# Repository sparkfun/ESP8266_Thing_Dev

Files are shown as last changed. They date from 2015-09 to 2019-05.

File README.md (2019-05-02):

SparkFun ESP8266 Thing Development Board
========================================

SparkFun ESP8266 Thing Development Board

[*SparkFun ESP8266 Thing Development Board  (WRL-13711)*](https://www.sparkfun.com/products/13711)

The [SparkFun ESP8266 Thing Development Board](https://www.sparkfun.com/products/13711) is a breakout and development board for the ESP8266 WiFi SoC. Why the name? We lovingly call it the Thing because it's the perfect foundation for your Internet of Things (IoT) project. The ESP8266 is an extremely cost-effective WiFi module, that can be programmed just like any microcontroller, and wiggle I/O while it communicates with the world-wide-web.

This version of the [Thing](https://www.sparkfun.com/products/13231) equips the ESP8266 with an **onboard FTDI FT231X**, which is used to program the chip over a USB interface. No external programming board required! The ESP8266's I/O pins are broken out to two parallel, breadboard-compatible rows. And LEDs towards the inside of the board indicate power, communication, and status of the IC. The ESP8266’s maximum voltage is 3.6V, so the Thing Development Board has an onboard 3.3V regulator to deliver a safe, consistent voltage to the IC. That means the ESP8266’s I/O pins also run at 3.3V, you’ll need to level shift any 5V signals running into the IC.

Repository Contents
-------------------

* **/Hardware** - Eagle design files (.brd, .sch)
* **/Production** - Production panel files (.brd)

Documentation
--------------
* **[Hookup Guide](https://learn.sparkfun.com/tutorials/esp8266-thing-development-board-hookup-guide)** - Exhaustive hookup guide for the ESP8266 Thing Development Board.

Product Versions
----------------

* [KIT-15259](https://www.sparkfun.com/products/15259)- ESP8266 Thing Development Board in a starter kit.
* [WRL-13804](https://www.sparkfun.com/products/13804)- ESP8266 Thing Development Board with headers.
* [WRL-13711](https://www.sparkfun.com/products/13711)- V1.0 release of the ESP8266 Thing Development Board.

License Information
-------------------

This product is _**open source**_! 

Please review the LICENSE.md file for license information. 

If you have any questions or concerns on licensing, please contact techsupport@sparkfun.com.

Please use, reuse, and modify these files as you see fit. Please maintain attribution to SparkFun Electronics and release anyThing Development Board derivative under the same license.

Distributed as-is; no warranty is given.

- Your friends at SparkFun.

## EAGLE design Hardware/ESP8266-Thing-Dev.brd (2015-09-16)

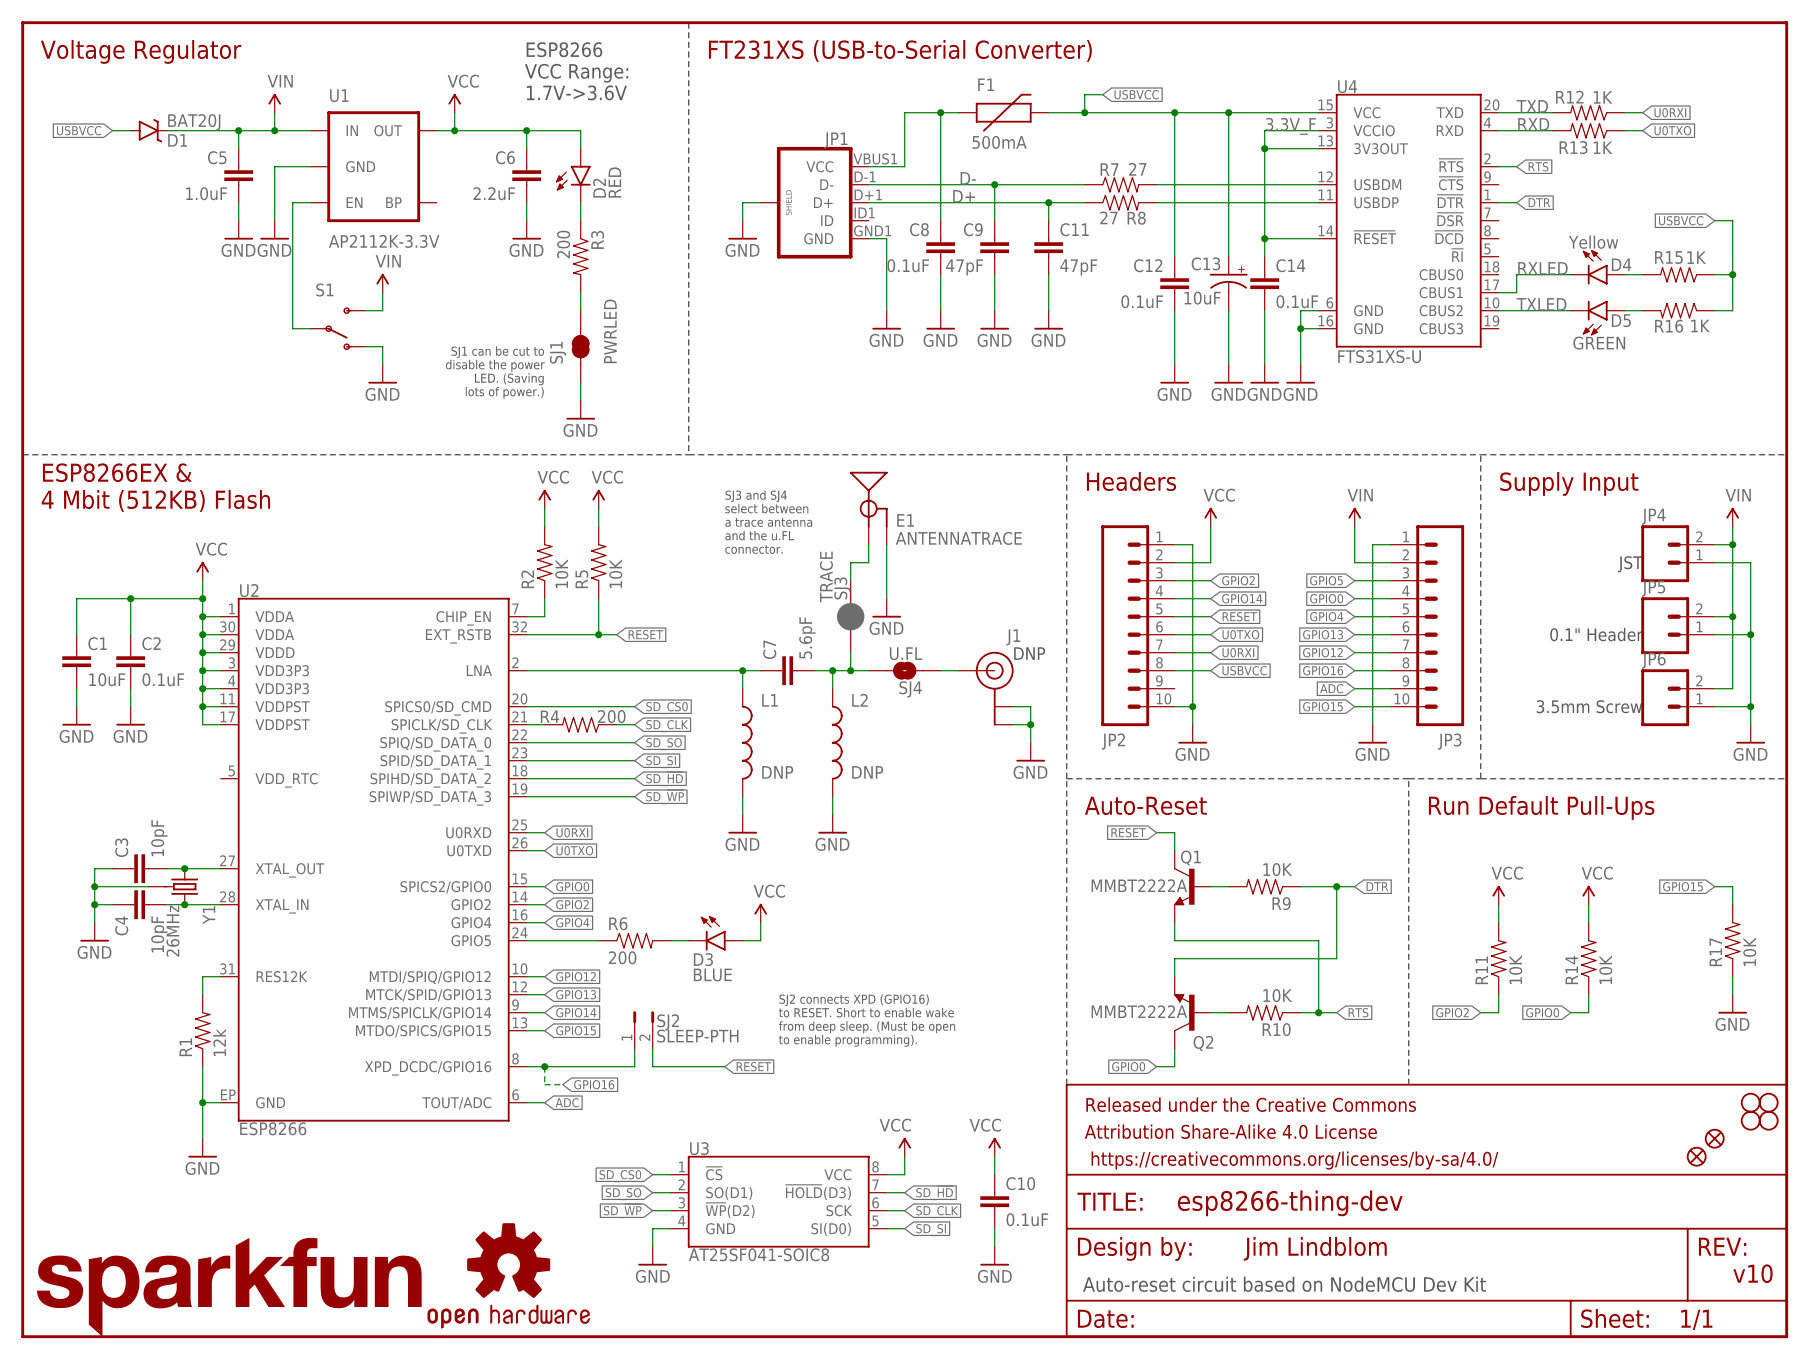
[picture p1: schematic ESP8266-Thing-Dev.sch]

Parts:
C1: 10uF; 0603-CAP
C2, C8, C10, C12, C14: 0.1uF; 0603-CAP
C3, C4: 10pF; 0603-CAP
C5: 1.0uF; 0805
C6: 2.2uF; 0603-CAP
C7: 5.6pF; 0603-CAP
C9, C11: 47pF; 0603-CAP
C13: 10uF; EIA3216
D1: BAT20J; SOD-323
D2: RED; LED-0603
D3: BLUE; LED-0603
D4: Yellow; LED-0603
D5: GREEN; LED-0603
E1: ANTENNATRACE; TRACE_ANTENNA_2.4GHZ_25.7MM
F1: 500mA; PTC-1206
FID1, FID2: FIDUCIAL1X2; FIDUCIAL-1X2
FRAME1: FRAME-LETTER; CREATIVE_COMMONS
J1: DNP; U.FL
JP1: USB_MICROB_PLUGCONN-11752; USB-B-MICRO-SMD_V03
JP2, JP3: M10NO_SILK_PTH_FEMALE; 1X10_NO_SILK
JP4: M02JST-PTH-2; JST-2-PTH
JP5: M021X02_NO_SILK; 1X02_NO_SILK
JP6: M023.5MM-NO_SILK; SCREWTERMINAL-3.5MM-2-NS
L1, L2: DNP; 0603
LOGO1: SFE_LOGO_NAME.2_INCH; SFE_LOGO_NAME_.2
LOGO2: OSHW-LOGOS; OSHW-LOGO-S
Q1, Q2: MMBT2222A; SOT23-3
R1: 12k; 0603-RES
R2, R5, R9, R10, R11, R14, R17: 10K; 0603-RES
R3, R4, R6: 200; 0603-RES
R7, R8: 27; 0603-RES
R12, R13, R15, R16: 1K; 0603-RES
S1: SWITCH-SPDT-SMD-A; SWITCH-SPST-SMD-A
SJ1: PWRLED; PAD-JUMPER-2-NC_BY_TRACE_YES_SILK
SJ2: SLEEP-PTH; PTH-JUMPER-2-NO_NO_SILK
SJ3: TRACE; PAD-JUMPER-2-NC_BY_PASTE_NO_SILK
SJ4: U.FL; PAD-JUMPER-2-NO_NO_SILK
STANDOFF1, STANDOFF2, STANDOFF3, STANDOFF4: STAND-OFF
U1: AP2112K-3.3V; SOT23-5
U2: ESP8266; QFN32
U3: AT25SF041-SOIC8; SO08
U4: FTS31XS-U; SSOP20_L
Y1: 26MHz; CRYSTAL-SMD-3.2X2.5

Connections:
3.3V_F: C14.1, U4.3 (VCCIO), U4.13 (3V3OUT), U4.14 (!RESET)
ADC: JP3.9, U2.6 (TOUT/ADC)
ANT: J1.P$3 (SIGNAL), SJ4.1
CHIP_EN: R2.1, U2.7 (CHIP_EN)
D+: C11.1, JP1.D+1 (D+), R8.1
D-: C9.1, JP1.D-1 (D-), R7.1
DTR: Q2.2 (E), R9.1, U4.1 (!DTR)
GND: C1.2, C2.2, C3.1, C4.1, C5.2, C6.2, C8.2, C9.2, C10.2, C11.2, C12.2, C13.C (-), C14.2, E1.GND, E1.GND2 (GND), J1.P$1 (GND), J1.P$2 (GND), JP1.GND1 (GND), JP1.SHIELD1 (SHIELD), JP1.SHIELD2 (SHIELD), JP1.SHIELD3 (SHIELD), JP2.1, JP2.10, JP3.1, JP4.1, JP5.1, JP6.1, L1.2, L2.2, R1.1, R17.1, S1.1 (O), SJ1.1, U1.2 (GND), U2.EP (GND), U3.4 (GND), U4.6 (GND), U4.16 (GND), Y1.2 (GND), Y1.4 (GND)
GPIO0: JP3.4, Q2.3 (C), R14.1, U2.15 (SPICS2/GPIO0)
GPIO2: JP2.3, R11.1, U2.14 (GPIO2)
GPIO4: JP3.5, U2.16 (GPIO4)
GPIO5: JP3.3, R6.1, U2.24 (GPIO5)
GPIO12: JP3.7, U2.10 (MTDI/SPIQ/GPIO12)
GPIO13: JP3.6, U2.12 (MTCK/SPID/GPIO13)
GPIO14: JP2.4, U2.9 (MTMS/SPICLK/GPIO14)
GPIO15: JP3.10, R17.2, U2.13 (MTDO/SPICS/GPIO15)
GPIO16: JP3.8, SJ2.1, U2.8 (XPD_DCDC/GPIO16)
LNA: C7.1, L1.1, U2.2 (LNA)
LNA2: C7.2, L2.1, SJ3.1, SJ4.2
unnamed: R1.2, U2.31 (RES12K)
unnamed: C4.2, U2.28 (XTAL_IN), Y1.3 (2)
unnamed: C3.2, U2.27 (XTAL_OUT), Y1.1
unnamed: R7.2, U4.12 (USBDM)
unnamed: R3.2, SJ1.2
unnamed: Q1.1 (B), R9.2
unnamed: R8.2, U4.11 (USBDP)
unnamed: D5.A, R16.2
unnamed: D3.C, R6.2
unnamed: D4.A, R15.2
unnamed: D2.C, R3.1
unnamed: Q2.1 (B), R10.2
unnamed: S1.2, U1.3 (EN)
RESET: JP2.5, Q1.3 (C), R5.1, SJ2.2, U2.32 (EXT_RSTB)
RTS: Q1.2 (E), R10.1, U4.2 (!RTS)
RXD: R13.2, U4.4 (RXD)
RXLED: D4.C, U4.17 (CBUS1)
SD_!HD!: U2.18 (SPIHD/SD_DATA_2), U3.7 (!HOLD!(D3))
SD_!WP!: U2.19 (SPIWP/SD_DATA_3), U3.3 (!WP!(D2))
SD_CLK: R4.1, U3.6 (SCK)
SD_CLK0: R4.2, U2.21 (SPICLK/SD_CLK)
SD_CS0: U2.20 (SPICS0/SD_CMD), U3.1 (!CS!)
SD_SI: U2.23 (SPID/SD_DATA_1), U3.5 (SI(D0))
SD_SO: U2.22 (SPIQ/SD_DATA_0), U3.2 (SO(D1))
TRACE_ANT: E1.ANT (SIGNAL), SJ3.2
TXD: R12.2, U4.20 (TXD)
TXLED: D5.C, U4.10 (CBUS2)
U0RXI: JP2.7, R12.1, U2.25 (U0RXD)
U0TXO: JP2.6, R13.1, U2.26 (U0TXD)
USBVCC: C12.1, C13.A (+), D1.A, F1.2, JP2.8, R15.1, R16.1, U4.15 (VCC)
VCC: C1.1, C2.1, C6.1, C10.1, D2.A, D3.A, JP2.2, R2.2, R5.2, R11.2, R14.2, U1.5 (OUT), U2.1 (VDDA), U2.3 (VDD3P3), U2.4 (VDD3P3), U2.11 (VDDPST), U2.17 (VDDPST), U2.29 (VDDD), U2.30 (VDDA), U3.8 (VCC)
VIN: C5.1, D1.C, JP3.2, JP4.2, JP5.2, JP6.2, S1.3 (S), U1.1 (IN)
VUSB: C8.1, F1.1, JP1.VBUS1 (VCC)

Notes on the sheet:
ESP8266EX & 4 Mbit (512KB) Flash
ESP8266 VCC Range: 1.7V->3.6V
Voltage Regulator
FT231XS (USB-to-Serial Converter)
Headers
Auto-Reset
Supply Input
JST
0.1" Header
3.5mm Screw
Run Default Pull-Ups
SJ2 connects XPD (GPIO16) to RESET. Short to enable wake from deep sleep. (Must be open to enable programming).
SJ1 can be cut to disable the power LED. (Saving lots of power.)
Jim Lindblom
v10
DNP
Auto-reset circuit based on NodeMCU Dev Kit
SJ3 and SJ4 select between a trace antenna and the u.FL connector.

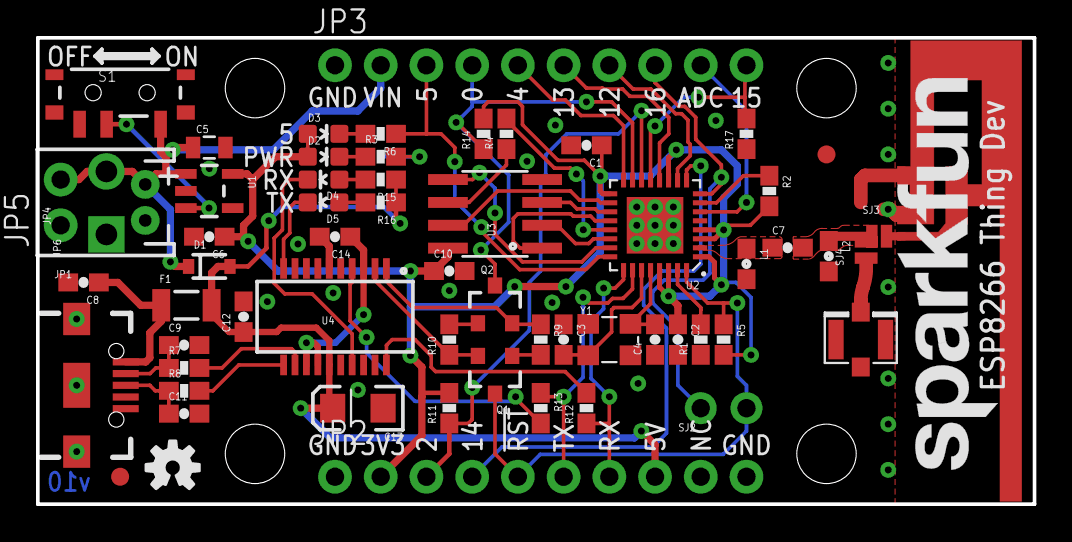
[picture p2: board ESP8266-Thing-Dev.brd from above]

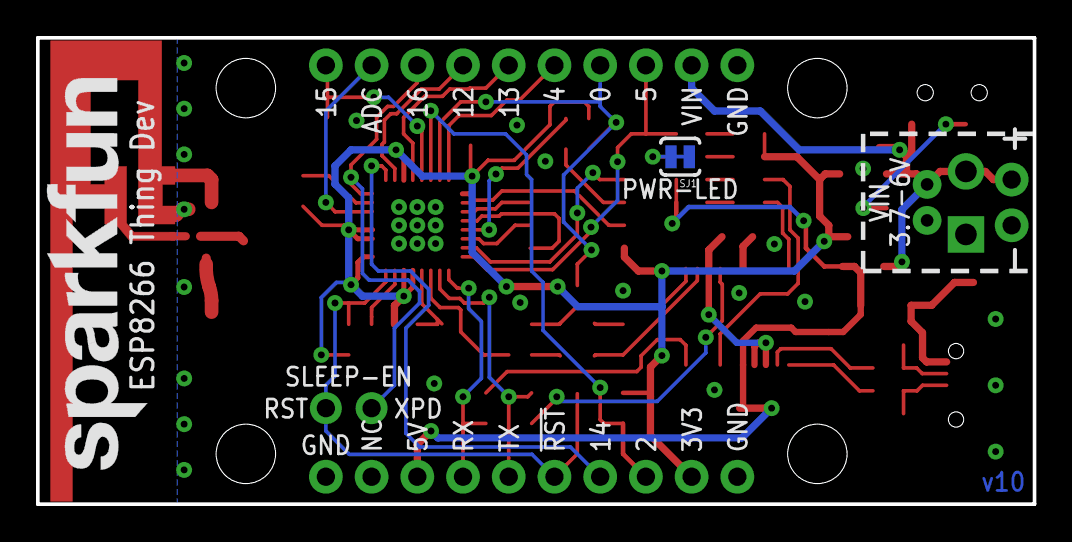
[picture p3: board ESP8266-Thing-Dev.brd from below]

Board: 2 copper layers, 55.4 x 25.9 mm, 69 parts (2 on the bottom side), 52 nets.

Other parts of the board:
LOGO3: SFE_LOGO_NAME.2_INCH; SFE_LOGO_NAME_.2

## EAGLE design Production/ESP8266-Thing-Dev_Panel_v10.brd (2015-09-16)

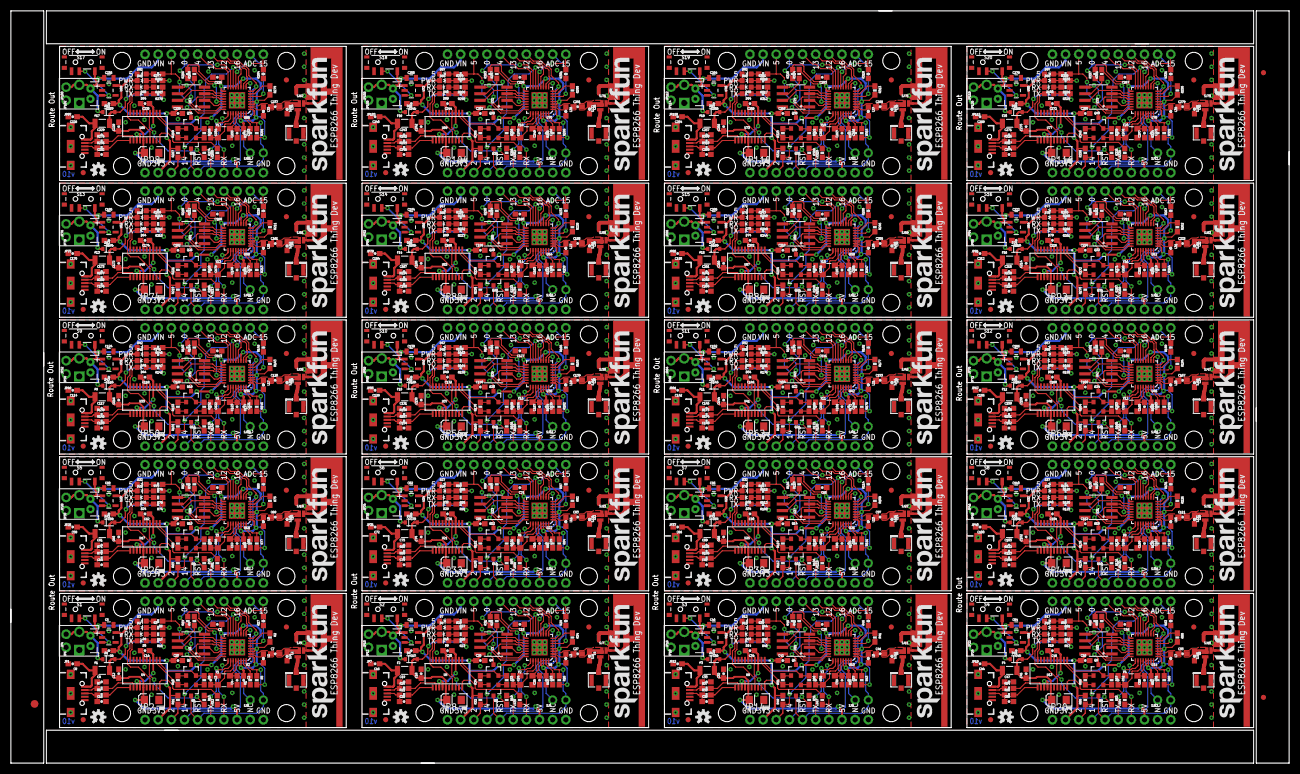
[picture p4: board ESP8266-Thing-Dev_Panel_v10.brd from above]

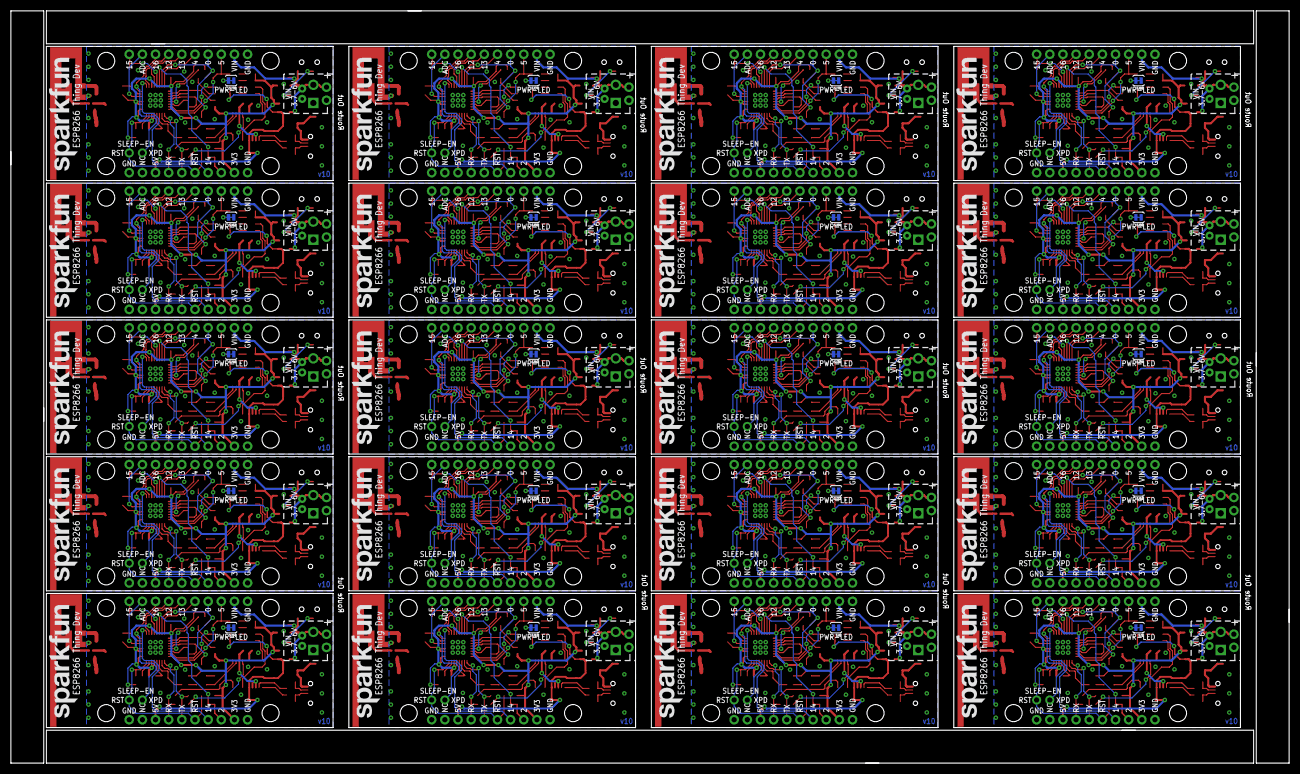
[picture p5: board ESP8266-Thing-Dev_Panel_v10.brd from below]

Board: 2 copper layers, 246.9 x 145.3 mm, 1363 parts (40 on the bottom side), 1040 nets.

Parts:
C1, C15, C29, C43, C57, C71, C85, C99, C113, C127, C141, C155, C169, C183, C197, C211, C225, C239, C253, C267: 10uF; 0603-CAP
C2, C8, C10, C12, C14, C16, C18, C20, C23, C28, C30, C32, C34, C37, C42, C44, C46, C48, C51, C56, C58, C60, C62, C65, C70, C72, C74, C76, C79, C84, C86, C88, C90, C93, C98, C100, C102, C104, C107, C112, C114, C116, C118, C121, C126, C128, C130, C132, C135, C140, C142, C144, C146, C149, C154, C156, C158, C160, C163, C168, C170, C172, C174, C177, C182, C184, C186, C188, C191, C196, C198, C200, C202, C205, C210, C212, C214, C216, C219, C224, C226, C228, C230, C233, C238, C240, C242, C244, C247, C252, C254, C256, C258, C261, C266, C268, C270, C272, C275, C280: 0.1uF; 0603-CAP
C3, C4, C24, C25, C38, C39, C52, C53, C66, C67, C80, C81, C94, C95, C108, C109, C122, C123, C136, C137, C150, C151, C164, C165, C178, C179, C192, C193, C206, C207, C220, C221, C234, C235, C248, C249, C262, C263, C276, C277: 10pF; 0603-CAP
C5, C26, C40, C54, C68, C82, C96, C110, C124, C138, C152, C166, C180, C194, C208, C222, C236, C250, C264, C278: 1.0uF; 0805
C6, C17, C31, C45, C59, C73, C87, C101, C115, C129, C143, C157, C171, C185, C199, C213, C227, C241, C255, C269: 2.2uF; 0603-CAP
C7, C27, C41, C55, C69, C83, C97, C111, C125, C139, C153, C167, C181, C195, C209, C223, C237, C251, C265, C279: 5.6pF; 0603-CAP
C9, C11, C19, C22, C33, C36, C47, C50, C61, C64, C75, C78, C89, C92, C103, C106, C117, C120, C131, C134, C145, C148, C159, C162, C173, C176, C187, C190, C201, C204, C215, C218, C229, C232, C243, C246, C257, C260, C271, C274: 47pF; 0603-CAP
C13, C21, C35, C49, C63, C77, C91, C105, C119, C133, C147, C161, C175, C189, C203, C217, C231, C245, C259, C273: 10uF; EIA3216
D1, D8, D13, D18, D23, D28, D33, D38, D43, D48, D53, D58, D63, D68, D73, D78, D83, D88, D93, D98: BAT20J; SOD-323
D2, D6, D11, D16, D21, D26, D31, D36, D41, D46, D51, D56, D61, D66, D71, D76, D81, D86, D91, D96: RED; LED-0603
D3, D7, D12, D17, D22, D27, D32, D37, D42, D47, D52, D57, D62, D67, D72, D77, D82, D87, D92, D97: BLUE; LED-0603
D4, D10, D15, D20, D25, D30, D35, D40, D45, D50, D55, D60, D65, D70, D75, D80, D85, D90, D95, D100: Yellow; LED-0603
D5, D9, D14, D19, D24, D29, D34, D39, D44, D49, D54, D59, D64, D69, D74, D79, D84, D89, D94, D99: GREEN; LED-0603
E1, E2, E3, E4, E5, E6, E7, E8, E9, E10, E11, E12, E13, E14, E15, E16, E17, E18, E19, E20: ANTENNATRACE; TRACE_ANTENNA_2.4GHZ_25.7MM
E$1: FIDUCIAL-1.5X3
E$7, E$8: FIDUCIAL-1X2
F1, F2, F3, F4, F5, F6, F7, F8, F9, F10, F11, F12, F13, F14, F15, F16, F17, F18, F19, F20: 500mA; PTC-1206
FID1, FID2, FID3, FID4, FID5, FID6, FID7, FID8, FID9, FID10, FID11, FID12, FID13, FID14, FID15, FID16, FID17, FID18, FID19, FID20, FID21, FID22, FID23, FID24, FID25, FID26, FID27, FID28, FID29, FID30, FID31, FID32, FID33, FID34, FID35, FID36, FID37, FID38, FID39, FID40: FIDUCIAL1X2; FIDUCIAL-1X2
J1, J2, J3, J4, J5, J6, J7, J8, J9, J10, J11, J12, J13, J14, J15, J16, J17, J18, J19, J20: DNP; U.FL
JP1, JP7, JP13, JP19, JP25, JP31, JP37, JP43, JP49, JP55, JP61, JP67, JP73, JP79, JP85, JP91, JP97, JP103, JP109, JP115: USB-B-MICRO-SMD_V03
JP2, JP3, JP8, JP9, JP14, JP15, JP20, JP21, JP26, JP27, JP32, JP33, JP38, JP39, JP44, JP45, JP50, JP51, JP56, JP57, JP62, JP63, JP68, JP69, JP74, JP75, JP80, JP81, JP86, JP87, JP92, JP93, JP98, JP99, JP104, JP105, JP110, JP111, JP116, JP117: 1X10_NO_SILK
JP4, JP10, JP16, JP22, JP28, JP34, JP40, JP46, JP52, JP58, JP64, JP70, JP76, JP82, JP88, JP94, JP100, JP106, JP112, JP118: JST-2-PTH
JP5, JP11, JP17, JP23, JP29, JP35, JP41, JP47, JP53, JP59, JP65, JP71, JP77, JP83, JP89, JP95, JP101, JP107, JP113, JP119: 1X02_NO_SILK
JP6, JP12, JP18, JP24, JP30, JP36, JP42, JP48, JP54, JP60, JP66, JP72, JP78, JP84, JP90, JP96, JP102, JP108, JP114, JP120: SCREWTERMINAL-3.5MM-2-NS
L1, L2, L3, L4, L5, L6, L7, L8, L9, L10, L11, L12, L13, L14, L15, L16, L17, L18, L19, L20, L21, L22, L23, L24, L25, L26, L27, L28, L29, L30, L31, L32, L33, L34, L35, L36, L37, L38, L39, L40: DNP; 0603
LOGO1, LOGO3, LOGO4, LOGO6, LOGO7, LOGO9, LOGO10, LOGO12, LOGO13, LOGO15, LOGO16, LOGO18, LOGO19, LOGO21, LOGO22, LOGO24, LOGO25, LOGO27, LOGO28, LOGO30, LOGO31, LOGO33, LOGO34, LOGO36, LOGO37, LOGO39, LOGO40, LOGO42, LOGO43, LOGO45, LOGO46, LOGO48, LOGO49, LOGO51, LOGO52, LOGO54, LOGO55, LOGO57, LOGO58, LOGO60: SFE_LOGO_NAME.2_INCH; SFE_LOGO_NAME_.2
LOGO2, LOGO5, LOGO8, LOGO11, LOGO14, LOGO17, LOGO20, LOGO23, LOGO26, LOGO29, LOGO32, LOGO35, LOGO38, LOGO41, LOGO44, LOGO47, LOGO50, LOGO53, LOGO56, LOGO59: OSHW-LOGOS; OSHW-LOGO-S
Q1, Q2, Q3, Q4, Q5, Q6, Q7, Q8, Q9, Q10, Q11, Q12, Q13, Q14, Q15, Q16, Q17, Q18, Q19, Q20, Q21, Q22, Q23, Q24, Q25, Q26, Q27, Q28, Q29, Q30, Q31, Q32, Q33, Q34, Q35, Q36, Q37, Q38, Q39, Q40: MMBT2222A; SOT23-3
R1, R18, R35, R52, R69, R86, R103, R120, R137, R154, R171, R188, R205, R222, R239, R256, R273, R290, R307, R324: 12k; 0603-RES
R2, R5, R9, R10, R11, R14, R17, R24, R26, R29, R31, R32, R33, R34, R41, R43, R46, R48, R49, R50, R51, R58, R60, R63, R65, R66, R67, R68, R75, R77, R80, R82, R83, R84, R85, R92, R94, R97, R99, R100, R101, R102, R109, R111, R114, R116, R117, R118, R119, R126, R128, R131, R133, R134, R135, R136, R143, R145, R148, R150, R151, R152, R153, R160, R162, R165, R167, R168, R169, R170, R177, R179, R182, R184, R185, R186, R187, R194, R196, R199, R201, R202, R203, R204, R211, R213, R216, R218, R219, R220, R221, R228, R230, R233, R235, R236, R237, R238, R245, R247, R250, R252, R253, R254, R255, R262, R264, R267, R269, R270, R271, R272, R279, R281, R284, R286, R287, R288, R289, R296, R298, R301, R303, R304, R305, R306, R313, R315, R318, R320, R321, R322, R323, R330, R332, R335, R337, R338, R339, R340: 10K; 0603-RES
R3, R4, R6, R22, R25, R27, R39, R42, R44, R56, R59, R61, R73, R76, R78, R90, R93, R95, R107, R110, R112, R124, R127, R129, R141, R144, R146, R158, R161, R163, R175, R178, R180, R192, R195, R197, R209, R212, R214, R226, R229, R231, R243, R246, R248, R260, R263, R265, R277, R280, R282, R294, R297, R299, R311, R314, R316, R328, R331, R333: 200; 0603-RES
R7, R8, R20, R21, R37, R38, R54, R55, R71, R72, R88, R89, R105, R106, R122, R123, R139, R140, R156, R157, R173, R174, R190, R191, R207, R208, R224, R225, R241, R242, R258, R259, R275, R276, R292, R293, R309, R310, R326, R327: 27; 0603-RES
R12, R13, R15, R16, R19, R23, R28, R30, R36, R40, R45, R47, R53, R57, R62, R64, R70, R74, R79, R81, R87, R91, R96, R98, R104, R108, R113, R115, R121, R125, R130, R132, R138, R142, R147, R149, R155, R159, R164, R166, R172, R176, R181, R183, R189, R193, R198, R200, R206, R210, R215, R217, R223, R227, R232, R234, R240, R244, R249, R251, R257, R261, R266, R268, R274, R278, R283, R285, R291, R295, R300, R302, R308, R312, R317, R319, R325, R329, R334, R336: 1K; 0603-RES
S1, S2, S3, S4, S5, S6, S7, S8, S9, S10, S11, S12, S13, S14, S15, S16, S17, S18, S19, S20: SWITCH-SPST-SMD-A
SJ1, SJ6, SJ10, SJ14, SJ18, SJ22, SJ26, SJ30, SJ34, SJ38, SJ42, SJ46, SJ50, SJ54, SJ58, SJ62, SJ66, SJ70, SJ74, SJ78: PWRLED; PAD-JUMPER-2-NC_BY_TRACE_YES_SILK
SJ2, SJ5, SJ9, SJ13, SJ17, SJ21, SJ25, SJ29, SJ33, SJ37, SJ41, SJ45, SJ49, SJ53, SJ57, SJ61, SJ65, SJ69, SJ73, SJ77: SLEEP-PTH; PTH-JUMPER-2-NO_NO_SILK
SJ3, SJ7, SJ11, SJ15, SJ19, SJ23, SJ27, SJ31, SJ35, SJ39, SJ43, SJ47, SJ51, SJ55, SJ59, SJ63, SJ67, SJ71, SJ75, SJ79: TRACE; PAD-JUMPER-2-NC_BY_PASTE_NO_SILK
SJ4, SJ8, SJ12, SJ16, SJ20, SJ24, SJ28, SJ32, SJ36, SJ40, SJ44, SJ48, SJ52, SJ56, SJ60, SJ64, SJ68, SJ72, SJ76, SJ80: U.FL; PAD-JUMPER-2-NO_NO_SILK
STANDOFF1, STANDOFF2, STANDOFF3, STANDOFF4, STANDOFF5, STANDOFF6, STANDOFF7, STANDOFF8, STANDOFF9, STANDOFF10, STANDOFF11, STANDOFF12, STANDOFF13, STANDOFF14, STANDOFF15, STANDOFF16, STANDOFF17, STANDOFF18, STANDOFF19, STANDOFF20, STANDOFF21, STANDOFF22, STANDOFF23, STANDOFF24, STANDOFF25, STANDOFF26, STANDOFF27, STANDOFF28, STANDOFF29, STANDOFF30, STANDOFF31, STANDOFF32, STANDOFF33, STANDOFF34, STANDOFF35, STANDOFF36, STANDOFF37, STANDOFF38, STANDOFF39, STANDOFF40, STANDOFF41, STANDOFF42, STANDOFF43, STANDOFF44, STANDOFF45, STANDOFF46, STANDOFF47, STANDOFF48, STANDOFF49, STANDOFF50, STANDOFF51, STANDOFF52, STANDOFF53, STANDOFF54, STANDOFF55, STANDOFF56, STANDOFF57, STANDOFF58, STANDOFF59, STANDOFF60, STANDOFF61, STANDOFF62, STANDOFF63, STANDOFF64, STANDOFF65, STANDOFF66, STANDOFF67, STANDOFF68, STANDOFF69, STANDOFF70, STANDOFF71, STANDOFF72, STANDOFF73, STANDOFF74, STANDOFF75, STANDOFF76, STANDOFF77, STANDOFF78, STANDOFF79, STANDOFF80: STAND-OFF
U1, U8, U12, U16, U20, U24, U28, U32, U36, U40, U44, U48, U52, U56, U60, U64, U68, U72, U76, U80: AP2112K-3.3V; SOT23-5
U2, U6, U10, U14, U18, U22, U26, U30, U34, U38, U42, U46, U50, U54, U58, U62, U66, U70, U74, U78: ESP8266; QFN32
U3, U7, U11, U15, U19, U23, U27, U31, U35, U39, U43, U47, U51, U55, U59, U63, U67, U71, U75, U79: AT25SF041-SOIC8; SO08
U4, U5, U9, U13, U17, U21, U25, U29, U33, U37, U41, U45, U49, U53, U57, U61, U65, U69, U73, U77: FTS31XS-U; SSOP20_L
Y1, Y2, Y3, Y4, Y5, Y6, Y7, Y8, Y9, Y10, Y11, Y12, Y13, Y14, Y15, Y16, Y17, Y18, Y19, Y20: 26MHz; CRYSTAL-SMD-3.2X2.5

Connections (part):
3.3V_F: C14.1, U4.3, U4.13, U4.14
3.3V_F1: C20.1, U5.3, U5.13, U5.14
3.3V_F2: C34.1, U9.3, U9.13, U9.14
3.3V_F3: C48.1, U13.3, U13.13, U13.14
3.3V_F4: C62.1, U17.3, U17.13, U17.14
3.3V_F5: C76.1, U21.3, U21.13, U21.14
3.3V_F6: C90.1, U25.3, U25.13, U25.14
3.3V_F7: C104.1, U29.3, U29.13, U29.14
3.3V_F8: C118.1, U33.3, U33.13, U33.14
3.3V_F9: C132.1, U37.3, U37.13, U37.14
3.3V_F10: C146.1, U41.3, U41.13, U41.14
3.3V_F11: C160.1, U45.3, U45.13, U45.14
3.3V_F12: C174.1, U49.3, U49.13, U49.14
3.3V_F13: C188.1, U53.3, U53.13, U53.14
3.3V_F14: C202.1, U57.3, U57.13, U57.14
3.3V_F15: C216.1, U61.3, U61.13, U61.14
3.3V_F16: C230.1, U65.3, U65.13, U65.14
3.3V_F17: C244.1, U69.3, U69.13, U69.14
3.3V_F18: C258.1, U73.3, U73.13, U73.14
3.3V_F19: C272.1, U77.3, U77.13, U77.14
ADC: JP3.9, U2.6
ADC1: JP9.9, U6.6
ADC2: JP15.9, U10.6
ADC3: JP21.9, U14.6
ADC4: JP27.9, U18.6
ADC5: JP33.9, U22.6
ADC6: JP39.9, U26.6
ADC7: JP45.9, U30.6
ADC8: JP51.9, U34.6
ADC9: JP57.9, U38.6
ADC10: JP63.9, U42.6
ADC11: JP69.9, U46.6
ADC12: JP75.9, U50.6
ADC13: JP81.9, U54.6
ADC14: JP87.9, U58.6
ADC15: JP93.9, U62.6
ADC16: JP99.9, U66.6
ADC17: JP105.9, U70.6
ADC18: JP111.9, U74.6
ADC19: JP117.9, U78.6
ANT: J1.P$3, SJ4.1
ANT1: J2.P$3, SJ8.1
ANT2: J3.P$3, SJ12.1
ANT3: J4.P$3, SJ16.1
ANT4: J5.P$3, SJ20.1
ANT5: J6.P$3, SJ24.1
ANT6: J7.P$3, SJ28.1
ANT7: J8.P$3, SJ32.1
ANT8: J9.P$3, SJ36.1
ANT9: J10.P$3, SJ40.1
ANT10: J11.P$3, SJ44.1
ANT11: J12.P$3, SJ48.1
ANT12: J13.P$3, SJ52.1
ANT13: J14.P$3, SJ56.1
ANT14: J15.P$3, SJ60.1
ANT15: J16.P$3, SJ64.1
ANT16: J17.P$3, SJ68.1
ANT17: J18.P$3, SJ72.1
ANT18: J19.P$3, SJ76.1
ANT19: J20.P$3, SJ80.1
CHIP_EN: R2.1, U2.7
CHIP_EN1: R24.1, U6.7
CHIP_EN2: R41.1, U10.7
CHIP_EN3: R58.1, U14.7
CHIP_EN4: R75.1, U18.7
CHIP_EN5: R92.1, U22.7
CHIP_EN6: R109.1, U26.7
CHIP_EN7: R126.1, U30.7
CHIP_EN8: R143.1, U34.7
CHIP_EN9: R160.1, U38.7
CHIP_EN10: R177.1, U42.7
CHIP_EN11: R194.1, U46.7
CHIP_EN12: R211.1, U50.7
CHIP_EN13: R228.1, U54.7
CHIP_EN14: R245.1, U58.7
CHIP_EN15: R262.1, U62.7
CHIP_EN16: R279.1, U66.7
CHIP_EN17: R296.1, U70.7
CHIP_EN18: R313.1, U74.7
CHIP_EN19: R330.1, U78.7
D+: C11.1, JP1.D+1, R8.1
D+1: C22.1, JP7.D+1, R21.1
D+2: C36.1, JP13.D+1, R38.1
D+3: C50.1, JP19.D+1, R55.1
D+4: C64.1, JP25.D+1, R72.1
D+5: C78.1, JP31.D+1, R89.1
D+6: C92.1, JP37.D+1, R106.1
D+7: C106.1, JP43.D+1, R123.1
D+8: C120.1, JP49.D+1, R140.1
D+9: C134.1, JP55.D+1, R157.1
D+10: C148.1, JP61.D+1, R174.1
D+11: C162.1, JP67.D+1, R191.1
D+12: C176.1, JP73.D+1, R208.1
D+13: C190.1, JP79.D+1, R225.1
D+14: C204.1, JP85.D+1, R242.1
D+15: C218.1, JP91.D+1, R259.1
D+16: C232.1, JP97.D+1, R276.1
D+17: C246.1, JP103.D+1, R293.1
D+18: C260.1, JP109.D+1, R310.1
D+19: C274.1, JP115.D+1, R327.1
D-: C9.1, JP1.D-1, R7.1
D-1: C19.1, JP7.D-1, R20.1
D-2: C33.1, JP13.D-1, R37.1
D-3: C47.1, JP19.D-1, R54.1
D-4: C61.1, JP25.D-1, R71.1
D-5: C75.1, JP31.D-1, R88.1
D-6: C89.1, JP37.D-1, R105.1
D-7: C103.1, JP43.D-1, R122.1
D-8: C117.1, JP49.D-1, R139.1
D-9: C131.1, JP55.D-1, R156.1
D-10: C145.1, JP61.D-1, R173.1
D-11: C159.1, JP67.D-1, R190.1
D-12: C173.1, JP73.D-1, R207.1
D-13: C187.1, JP79.D-1, R224.1
D-14: C201.1, JP85.D-1, R241.1
D-15: C215.1, JP91.D-1, R258.1
D-16: C229.1, JP97.D-1, R275.1
D-17: C243.1, JP103.D-1, R292.1
D-18: C257.1, JP109.D-1, R309.1
D-19: C271.1, JP115.D-1, R326.1
DTR: Q2.2, R9.1, U4.1
DTR1: Q4.2, R33.1, U5.1
DTR2: Q6.2, R50.1, U9.1
DTR3: Q8.2, R67.1, U13.1
DTR4: Q10.2, R84.1, U17.1
DTR5: Q12.2, R101.1, U21.1
DTR6: Q14.2, R118.1, U25.1
DTR7: Q16.2, R135.1, U29.1
DTR8: Q18.2, R152.1, U33.1
DTR9: Q20.2, R169.1, U37.1
DTR10: Q22.2, R186.1, U41.1
DTR11: Q24.2, R203.1, U45.1
DTR12: Q26.2, R220.1, U49.1
DTR13: Q28.2, R237.1, U53.1
DTR14: Q30.2, R254.1, U57.1
DTR15: Q32.2, R271.1, U61.1
DTR16: Q34.2, R288.1, U65.1
DTR17: Q36.2, R305.1, U69.1
DTR18: Q38.2, R322.1, U73.1
DTR19: Q40.2, R339.1, U77.1
GND: C1.2, C2.2, C3.1, C4.1, C5.2, C6.2, C8.2, C9.2, C10.2, C11.2, C12.2, C13.C, C14.2, E1.GND, E1.GND2, J1.P$1, J1.P$2, JP1.GND1, JP1.SHIELD1, JP1.SHIELD2, JP1.SHIELD3, JP2.1, JP2.10, JP3.1, JP4.1, JP5.1, JP6.1, L1.2, L2.2, R1.1, R17.1, S1.1, SJ1.1, U1.2, U2.EP, U3.4, U4.6, U4.16, Y1.2, Y1.4
GND1: C15.2, C16.2, C17.2, C18.2, C19.2, C20.2, C21.C, C22.2, C23.2, C24.1, C25.1, C26.2, C28.2, E2.GND, E2.GND2, J2.P$1, J2.P$2, JP7.GND1, JP7.SHIELD1, JP7.SHIELD2, JP7.SHIELD3, JP8.1, JP8.10, JP9.1, JP10.1, JP11.1, JP12.1, L3.2, L4.2, R18.1, R29.1, S2.1, SJ6.1, U5.6, U5.16, U6.EP, U7.4, U8.2, Y2.2, Y2.4
GND2: C29.2, C30.2, C31.2, C32.2, C33.2, C34.2, C35.C, C36.2, C37.2, C38.1, C39.1, C40.2, C42.2, E3.GND, E3.GND2, J3.P$1, J3.P$2, JP13.GND1, JP13.SHIELD1, JP13.SHIELD2, JP13.SHIELD3, JP14.1, JP14.10, JP15.1, JP16.1, JP17.1, JP18.1, L5.2, L6.2, R35.1, R46.1, S3.1, SJ10.1, U9.6, U9.16, U10.EP, U11.4, U12.2, Y3.2, Y3.4
GND3: C43.2, C44.2, C45.2, C46.2, C47.2, C48.2, C49.C, C50.2, C51.2, C52.1, C53.1, C54.2, C56.2, E4.GND, E4.GND2, J4.P$1, J4.P$2, JP19.GND1, JP19.SHIELD1, JP19.SHIELD2, JP19.SHIELD3, JP20.1, JP20.10, JP21.1, JP22.1, JP23.1, JP24.1, L7.2, L8.2, R52.1, R63.1, S4.1, SJ14.1, U13.6, U13.16, U14.EP, U15.4, U16.2, Y4.2, Y4.4
GND4: C57.2, C58.2, C59.2, C60.2, C61.2, C62.2, C63.C, C64.2, C65.2, C66.1, C67.1, C68.2, C70.2, E5.GND, E5.GND2, J5.P$1, J5.P$2, JP25.GND1, JP25.SHIELD1, JP25.SHIELD2, JP25.SHIELD3, JP26.1, JP26.10, JP27.1, JP28.1, JP29.1, JP30.1, L9.2, L10.2, R69.1, R80.1, S5.1, SJ18.1, U17.6, U17.16, U18.EP, U19.4, U20.2, Y5.2, Y5.4
GND5: C71.2, C72.2, C73.2, C74.2, C75.2, C76.2, C77.C, C78.2, C79.2, C80.1, C81.1, C82.2, C84.2, E6.GND, E6.GND2, J6.P$1, J6.P$2, JP31.GND1, JP31.SHIELD1, JP31.SHIELD2, JP31.SHIELD3, JP32.1, JP32.10, JP33.1, JP34.1, JP35.1, JP36.1, L11.2, L12.2, R86.1, R97.1, S6.1, SJ22.1, U21.6, U21.16, U22.EP, U23.4, U24.2, Y6.2, Y6.4
GND6: C85.2, C86.2, C87.2, C88.2, C89.2, C90.2, C91.C, C92.2, C93.2, C94.1, C95.1, C96.2, C98.2, E7.GND, E7.GND2, J7.P$1, J7.P$2, JP37.GND1, JP37.SHIELD1, JP37.SHIELD2, JP37.SHIELD3, JP38.1, JP38.10, JP39.1, JP40.1, JP41.1, JP42.1, L13.2, L14.2, R103.1, R114.1, S7.1, SJ26.1, U25.6, U25.16, U26.EP, U27.4, U28.2, Y7.2, Y7.4
GND7: C99.2, C100.2, C101.2, C102.2, C103.2, C104.2, C105.C, C106.2, C107.2, C108.1, C109.1, C110.2, C112.2, E8.GND, E8.GND2, J8.P$1, J8.P$2, JP43.GND1, JP43.SHIELD1, JP43.SHIELD2, JP43.SHIELD3, JP44.1, JP44.10, JP45.1, JP46.1, JP47.1, JP48.1, L15.2, L16.2, R120.1, R131.1, S8.1, SJ30.1, U29.6, U29.16, U30.EP, U31.4, U32.2, Y8.2, Y8.4
GND8: C113.2, C114.2, C115.2, C116.2, C117.2, C118.2, C119.C, C120.2, C121.2, C122.1, C123.1, C124.2, C126.2, E9.GND, E9.GND2, J9.P$1, J9.P$2, JP49.GND1, JP49.SHIELD1, JP49.SHIELD2, JP49.SHIELD3, JP50.1, JP50.10, JP51.1, JP52.1, JP53.1, JP54.1, L17.2, L18.2, R137.1, R148.1, S9.1, SJ34.1, U33.6, U33.16, U34.EP, U35.4, U36.2, Y9.2, Y9.4
GND9: C127.2, C128.2, C129.2, C130.2, C131.2, C132.2, C133.C, C134.2, C135.2, C136.1, C137.1, C138.2, C140.2, E10.GND, E10.GND2, J10.P$1, J10.P$2, JP55.GND1, JP55.SHIELD1, JP55.SHIELD2, JP55.SHIELD3, JP56.1, JP56.10, JP57.1, JP58.1, JP59.1, JP60.1, L19.2, L20.2, R154.1, R165.1, S10.1, SJ38.1, U37.6, U37.16, U38.EP, U39.4, U40.2, Y10.2, Y10.4
GND10: C141.2, C142.2, C143.2, C144.2, C145.2, C146.2, C147.C, C148.2, C149.2, C150.1, C151.1, C152.2, C154.2, E11.GND, E11.GND2, J11.P$1, J11.P$2, JP61.GND1, JP61.SHIELD1, JP61.SHIELD2, JP61.SHIELD3, JP62.1, JP62.10, JP63.1, JP64.1, JP65.1, JP66.1, L21.2, L22.2, R171.1, R182.1, S11.1, SJ42.1, U41.6, U41.16, U42.EP, U43.4, U44.2, Y11.2, Y11.4
GND11: C155.2, C156.2, C157.2, C158.2, C159.2, C160.2, C161.C, C162.2, C163.2, C164.1, C165.1, C166.2, C168.2, E12.GND, E12.GND2, J12.P$1, J12.P$2, JP67.GND1, JP67.SHIELD1, JP67.SHIELD2, JP67.SHIELD3, JP68.1, JP68.10, JP69.1, JP70.1, JP71.1, JP72.1, L23.2, L24.2, R188.1, R199.1, S12.1, SJ46.1, U45.6, U45.16, U46.EP, U47.4, U48.2, Y12.2, Y12.4
GND12: C169.2, C170.2, C171.2, C172.2, C173.2, C174.2, C175.C, C176.2, C177.2, C178.1, C179.1, C180.2, C182.2, E13.GND, E13.GND2, J13.P$1, J13.P$2, JP73.GND1, JP73.SHIELD1, JP73.SHIELD2, JP73.SHIELD3, JP74.1, JP74.10, JP75.1, JP76.1, JP77.1, JP78.1, L25.2, L26.2, R205.1, R216.1, S13.1, SJ50.1, U49.6, U49.16, U50.EP, U51.4, U52.2, Y13.2, Y13.4
GND13: C183.2, C184.2, C185.2, C186.2, C187.2, C188.2, C189.C, C190.2, C191.2, C192.1, C193.1, C194.2, C196.2, E14.GND, E14.GND2, J14.P$1, J14.P$2, JP79.GND1, JP79.SHIELD1, JP79.SHIELD2, JP79.SHIELD3, JP80.1, JP80.10, JP81.1, JP82.1, JP83.1, JP84.1, L27.2, L28.2, R222.1, R233.1, S14.1, SJ54.1, U53.6, U53.16, U54.EP, U55.4, U56.2, Y14.2, Y14.4
GND14: C197.2, C198.2, C199.2, C200.2, C201.2, C202.2, C203.C, C204.2, C205.2, C206.1, C207.1, C208.2, C210.2, E15.GND, E15.GND2, J15.P$1, J15.P$2, JP85.GND1, JP85.SHIELD1, JP85.SHIELD2, JP85.SHIELD3, JP86.1, JP86.10, JP87.1, JP88.1, JP89.1, JP90.1, L29.2, L30.2, R239.1, R250.1, S15.1, SJ58.1, U57.6, U57.16, U58.EP, U59.4, U60.2, Y15.2, Y15.4
GND15: C211.2, C212.2, C213.2, C214.2, C215.2, C216.2, C217.C, C218.2, C219.2, C220.1, C221.1, C222.2, C224.2, E16.GND, E16.GND2, J16.P$1, J16.P$2, JP91.GND1, JP91.SHIELD1, JP91.SHIELD2, JP91.SHIELD3, JP92.1, JP92.10, JP93.1, JP94.1, JP95.1, JP96.1, L31.2, L32.2, R256.1, R267.1, S16.1, SJ62.1, U61.6, U61.16, U62.EP, U63.4, U64.2, Y16.2, Y16.4
GND16: C225.2, C226.2, C227.2, C228.2, C229.2, C230.2, C231.C, C232.2, C233.2, C234.1, C235.1, C236.2, C238.2, E17.GND, E17.GND2, J17.P$1, J17.P$2, JP97.GND1, JP97.SHIELD1, JP97.SHIELD2, JP97.SHIELD3, JP98.1, JP98.10, JP99.1, JP100.1, JP101.1, JP102.1, L33.2, L34.2, R273.1, R284.1, S17.1, SJ66.1, U65.6, U65.16, U66.EP, U67.4, U68.2, Y17.2, Y17.4
GND17: C239.2, C240.2, C241.2, C242.2, C243.2, C244.2, C245.C, C246.2, C247.2, C248.1, C249.1, C250.2, C252.2, E18.GND, E18.GND2, J18.P$1, J18.P$2, JP103.GND1, JP103.SHIELD1, JP103.SHIELD2, JP103.SHIELD3, JP104.1, JP104.10, JP105.1, JP106.1, JP107.1, JP108.1, L35.2, L36.2, R290.1, R301.1, S18.1, SJ70.1, U69.6, U69.16, U70.EP, U71.4, U72.2, Y18.2, Y18.4
GND18: C253.2, C254.2, C255.2, C256.2, C257.2, C258.2, C259.C, C260.2, C261.2, C262.1, C263.1, C264.2, C266.2, E19.GND, E19.GND2, J19.P$1, J19.P$2, JP109.GND1, JP109.SHIELD1, JP109.SHIELD2, JP109.SHIELD3, JP110.1, JP110.10, JP111.1, JP112.1, JP113.1, JP114.1, L37.2, L38.2, R307.1, R318.1, S19.1, SJ74.1, U73.6, U73.16, U74.EP, U75.4, U76.2, Y19.2, Y19.4
GND19: C267.2, C268.2, C269.2, C270.2, C271.2, C272.2, C273.C, C274.2, C275.2, C276.1, C277.1, C278.2, C280.2, E20.GND, E20.GND2, J20.P$1, J20.P$2, JP115.GND1, JP115.SHIELD1, JP115.SHIELD2, JP115.SHIELD3, JP116.1, JP116.10, JP117.1, JP118.1, JP119.1, JP120.1, L39.2, L40.2, R324.1, R335.1, S20.1, SJ78.1, U77.6, U77.16, U78.EP, U79.4, U80.2, Y20.2, Y20.4
GPIO0: JP3.4, Q2.3, R14.1, U2.15
GPIO1: JP8.4, U6.9
GPIO2: JP2.3, R11.1, U2.14
GPIO3: JP9.4, Q4.3, R31.1, U6.15
GPIO4: JP3.5, U2.16
GPIO5: JP3.3, R6.1, U2.24
GPIO6: JP9.3, R27.1, U6.24
GPIO7: JP9.5, U6.16
GPIO8: JP9.8, SJ5.1, U6.8
GPIO9: JP9.10, R29.2, U6.13
GPIO10: JP9.6, U6.12
GPIO11: JP9.7, U6.10
GPIO12: JP3.7, U2.10
GPIO13: JP3.6, U2.12
GPIO14: JP2.4, U2.9
GPIO15: JP3.10, R17.2, U2.13
GPIO16: JP3.8, SJ2.1, U2.8
GPIO17: JP8.3, R32.1, U6.14
GPIO18: JP14.4, U10.9
GPIO19: JP15.4, Q6.3, R48.1, U10.15
GPIO20: JP15.3, R44.1, U10.24
GPIO21: JP15.5, U10.16
GPIO22: JP15.8, SJ9.1, U10.8
GPIO23: JP15.10, R46.2, U10.13
GPIO24: JP15.6, U10.12
GPIO25: JP15.7, U10.10
GPIO26: JP14.3, R49.1, U10.14
GPIO27: JP20.4, U14.9
GPIO28: JP21.4, Q8.3, R65.1, U14.15
GPIO29: JP21.3, R61.1, U14.24
GPIO30: JP21.5, U14.16
GPIO31: JP21.8, SJ13.1, U14.8
GPIO32: JP21.10, R63.2, U14.13
GPIO33: JP21.6, U14.12
GPIO34: JP21.7, U14.10
GPIO35: JP20.3, R66.1, U14.14
GPIO36: JP26.4, U18.9
GPIO37: JP27.4, Q10.3, R82.1, U18.15
GPIO38: JP27.3, R78.1, U18.24
GPIO39: JP27.5, U18.16
GPIO40: JP27.8, SJ17.1, U18.8
GPIO41: JP27.10, R80.2, U18.13
GPIO42: JP27.6, U18.12
GPIO43: JP27.7, U18.10
GPIO44: JP26.3, R83.1, U18.14
GPIO45: JP32.4, U22.9
GPIO46: JP33.4, Q12.3, R99.1, U22.15
GPIO47: JP33.3, R95.1, U22.24
GPIO48: JP33.5, U22.16
GPIO49: JP33.8, SJ21.1, U22.8
GPIO50: JP33.10, R97.2, U22.13
GPIO51: JP33.6, U22.12
GPIO52: JP33.7, U22.10
GPIO53: JP32.3, R100.1, U22.14
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

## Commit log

2015-07-30 Initial commit of hardware.
    [ESP8266-Thing-Dev.brd, ESP8266-Thing-Dev.sch]
2015-08-05 Extending dimensions borders past antenna copper.
    [ESP8266-Thing-Dev.brd, ESP8266-Thing-Dev.sch]
2015-09-04 Removing SJ3 - SMD sleep jumper
    [ESP8266-Thing-Dev.brd, ESP8266-Thing-Dev.sch]
2015-09-14 Adjusting label header silk a bit
    [ESP8266-Thing-Dev.brd, ESP8266-Thing-Dev.sch]
2015-09-14 Fixing dimension lines
    [ESP8266-Thing-Dev.brd]
2015-09-14 Schematic cleanup, tweaking silkscreen
    [ESP8266-Thing-Dev.brd, ESP8266-Thing-Dev.sch]
2015-09-15 Last run-through, minor silk adjustments
    [ESP8266-Thing-Dev.brd]
2015-09-16 Bumping out dimensions to a 0.01in grid.
    [ESP8266-Thing-Dev.brd]
2015-09-16 moved fiducials inward for better recognition
    [ESP8266-Thing-Dev.brd]
2015-09-16 created panel v10
    [ESP8266-Thing-Dev_Panel_v10.brd]

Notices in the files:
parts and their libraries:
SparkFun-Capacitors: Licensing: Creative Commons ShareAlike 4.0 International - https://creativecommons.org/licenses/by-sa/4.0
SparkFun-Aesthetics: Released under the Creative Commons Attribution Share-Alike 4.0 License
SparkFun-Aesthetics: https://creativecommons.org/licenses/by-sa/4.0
